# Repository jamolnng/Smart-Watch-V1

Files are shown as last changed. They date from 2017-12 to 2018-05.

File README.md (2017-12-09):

# Smart Watch

An open source smart watch based on a PIC32 microcontroller. The original idea came from http://jared.geek.nz/2014/jul/oshw-oled-watch and many of the design ideas came from here

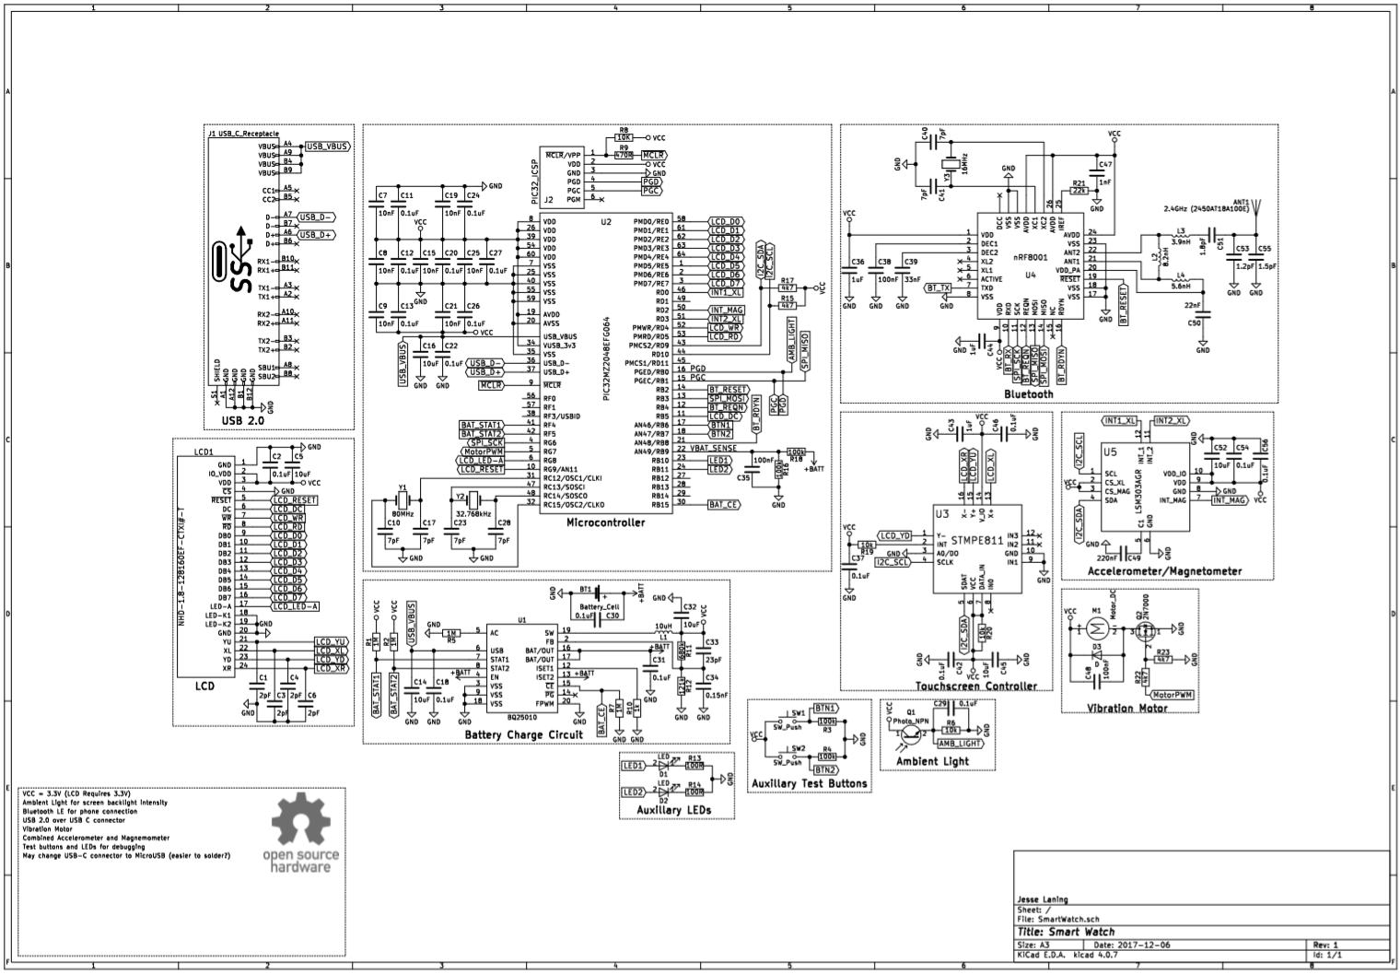
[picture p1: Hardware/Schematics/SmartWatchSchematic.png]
Schematic


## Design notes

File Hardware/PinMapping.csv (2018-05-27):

Physical Pin # | Full Pin Name | Pin Function |  | PPS |  |  | Notes
1 | AN17/ETXEN/RPE5/PMD5/RE5 | Input | Description | Pin Selection Register | Pin Selection Value | Physical Pin
2 | AN16/ETXD0/PMD6/RE6 | INT1_XL | Accelerometer Interrupt 1 | INT1R | 0011 | 46
3 | AN15/ETXD1/PMD7/RE7 | INT2_XL | Accelerometer Interrupt 2 | INT4R | 0000 | 51
4 | AN14/C1IND/RPG6/SCK2/PMA5/RG6 | INT_MAG | Magnemometer Interrupt | INT3R | 0000 | 50
5 | AN13/C1INC/RPG7/SDA4/PMA4/RG7 | BAT_STAT1 | Battery status pin 1 | RPF4R | 0000 | 41
6 | AN12/C2IND/RPG8/SCL4/PMA3/RG8 | BAT_STAT2 | Battery status pin 2 | RPF5R | 0000 | 42
7 | VSS | AMB_LIGHT | Ambient light analog input | RPB0R | 0000 | 16 | Analog/Do I really need this?
8 | VDD | BT_RDYN | ACI device ready indication | RPB8R | 0000 | 21 | Bluetooth: to figure out function
9 | MCLR | BTN1 | Button 1 input | PRB6R | 0000 | 17 | Do I really need these?
10 | AN11/C2INC/RPG9/PMA2/RG9 | BTN2 | Button 2 input | RPB7R | 0000 | 18
11 | AN45/C1INA/RPB5/RB5 | VBAT_SENSE | Battery voltage sense | × | × | 22 | Analog (AN49/RB9)
12 | AN4/C1INB/RB4 | T_INT | Touch Cont. Interrupt | RPF0R | 0000 | 56
13 | AN3/C2INA/RPB3/RB3
14 | AN2/C2INB/RPB2/RB2 | Output | Description | Pin Selection Register | Pin Selection Value | Physical Pin
15 | PGEC1/VREF-/CVREF-/AN1/RPB1/RB1 | BAT_CE | Battery charge enable | RPB15R | 0000 | 30
16 | PGED1/VREF+/CVREF+/AN0/RPB0/PMA6/RB0 | MotorPWM | Vibration Motor PWM | RPG7R | 1011 | 5
17 | PGEC2/AN46/RPB6/RB6 | LCD_LED-A | LCD Backlight Anode (PWM) | RPG8R | 1011 | 6
18 | PGED2/AN47/RPB7/RB7 | LCD_RESET | LCD Active LOW Reset | RPG9R | 0000 | 10
19 | AVDD | LCD_DC | LCD Data / Command selection | RPB5R | 0000 | 11
20 | AVSS | BT_REQN | ACI request pin | RPB4R | 0000 | 12 | Bluetooth: to figure out function
21 | AN48/RPB8/PMA10/RB8 | BT_RESET | Active LOW Reset Bluetooth | RPB2R | 0000 | 14
22 | AN49/RPB9/PMA7/RB9 | LED1 | LED 1 | RPB10R | 0000 | 23 | Do I really need these? (RB11 Not PPS)
23 | TMS/CVREFOUT/AN5/RPB10/PMA13/RB10 | LED2 | LED 2 | × | × | 24
24 | TDO/AN6/PMA12/RB11
25 | VSS | SPI | Description | Pin Selection Register | Pin Selection Value | Physical Pin
26 | VDD | SPI_SCK | SPI Clock | × | × | 4 | SPI 2 (pg. 26)
27 | TCK/AN7/PMA11/RB12 | SPI_MOSI | SPI MOSI | SDI2R | 0101 | 13
28 | TDI/AN8/RB13 | SPI_MISO | SPI MISO | RPB3R | 0110 | 15
29 | AN9/RPB14/SCK3/PMA1/RB14
30 | AN10/EMDC/AEMDC/RPB15/OCFB/PMA0/RB15 | I²C | Description | Pin Selection Register | Pin Selection Value | Physical Pin
31 | OSC1/CLKI/RC12 | I2C_SCL | I²C Clock (SCL) | × | × | 44 | I²C 1 (pg. 27)
32 | OSC2/CLKO/RC15 | I2C_SDA | I²C Data (SDA) | × | × | 43
33 | VBUS
34 | VUSB3v3 | PMP | Description | Pin Selection Register | Pin Selection Value | Physical Pin
35 | VSS | LCD_D0 | LCD Data 0 | × | × | 58
36 | D- | LCD_D1 | LCD Data 1 | × | × | 61
37 | D+ | LCD_D2 | LCD Data 2 | × | × | 62
38 | RPF3/USBID/RF3 | LCD_D3 | LCD Data 3 | × | × | 63
39 | VDD | LCD_D4 | LCD Data 4 | × | × | 64
40 | VSS | LCD_D5 | LCD Data 5 | × | × | 1
41 | RPF4/SDA5/PMA9/RF4 | LCD_D6 | LCD Data 6 | × | × | 2
42 | RPF5/SCL5/PMA8/RF5 | LCD_D7 | LCD Data 7 | × | × | 3
43 | AERXD0/ETXD2/RPD9/SDA1/PMCS2/PMA15/RD9 | LCD_WR | LCD Active LOW Write signal | × | × | 52
44 | ECOL/RPD10/SCL1/SCK4/RD10 | LCD_RD | LCD Active LOW Read signal | × | × | 53 | Will use on rev 1 because software might need to read from screen
45 | AERXCLK/AEREFCLK/ECRS/RPD11/PMCS1/PMA14/RD11
46 | AERXD1/ETXD3/RPD0/RTCC/INT0/RD0
47 | SOSCI/RPC13/RC13 | USB | Description | Pin Selection Register | Pin Selection Value | Physical Pin
48 | SOSCO/RPC14/T1CK/RC14 | D+ |  | × | × | 37
49 | EMDIO/AEMDIO/RPD1/SCK1/RD1 | D- |  | × | × | 36
50 | ETXERR/AETXEN/RPD2/SDA3/RD2
51 | AERXERR/ETXCLK/RPD3/SCL3/RD3 | ICSP | Description | Pin Selection Register | Pin Selection Value | Physical Pin
52 | SQICS0/RPD4/PMWR/RD4 | MCLR |  | × | × | 9 | Programming Pins
53 | SQICS1/RPD5/PMRD/RD5 | PGD |  | × | × | 16
54 | VDD | PGC |  | × | × | 15
55 | VSS
56 | ERXD3/AETXD1/RPF0/RF0 | INTERRUPTS | Description | Pin Selection Register | Pin Selection Value | Physical Pin
57 | TRCLK/SQICLK/ERXD2/AETXD0/RPF1/RF1 | INT0 | UNUSED | × | × | ×
58 | TRD0/SQID0/ERXD1/PMD0/RE0 | INT1 |  | INT1R | 0011 | 46
59 | VSS | INT2 | UNUSED | × | × | ×
60 | VDD | INT3 |  | INT3R | 0000 | 50
61 | TRD1/SQID1/ERXD0/PMD1/RE1 | INT4 |  | INT4R | 0000 | 51
62 | TRD2/SQID2/ERXDV/ECRSDV/AECRSDV/PMD2/RE2 |  |  |  |  |  | Probab gonna change processor and screen on rev 2 to support MIPI
63 | TRD3/SQID3/ERXCLK/EREFCLK/RPE3/PMD3/RE3
64 | AN18/ERXERR/PMD4/RE4 |  |  |  |  |  | PPS on pg 251

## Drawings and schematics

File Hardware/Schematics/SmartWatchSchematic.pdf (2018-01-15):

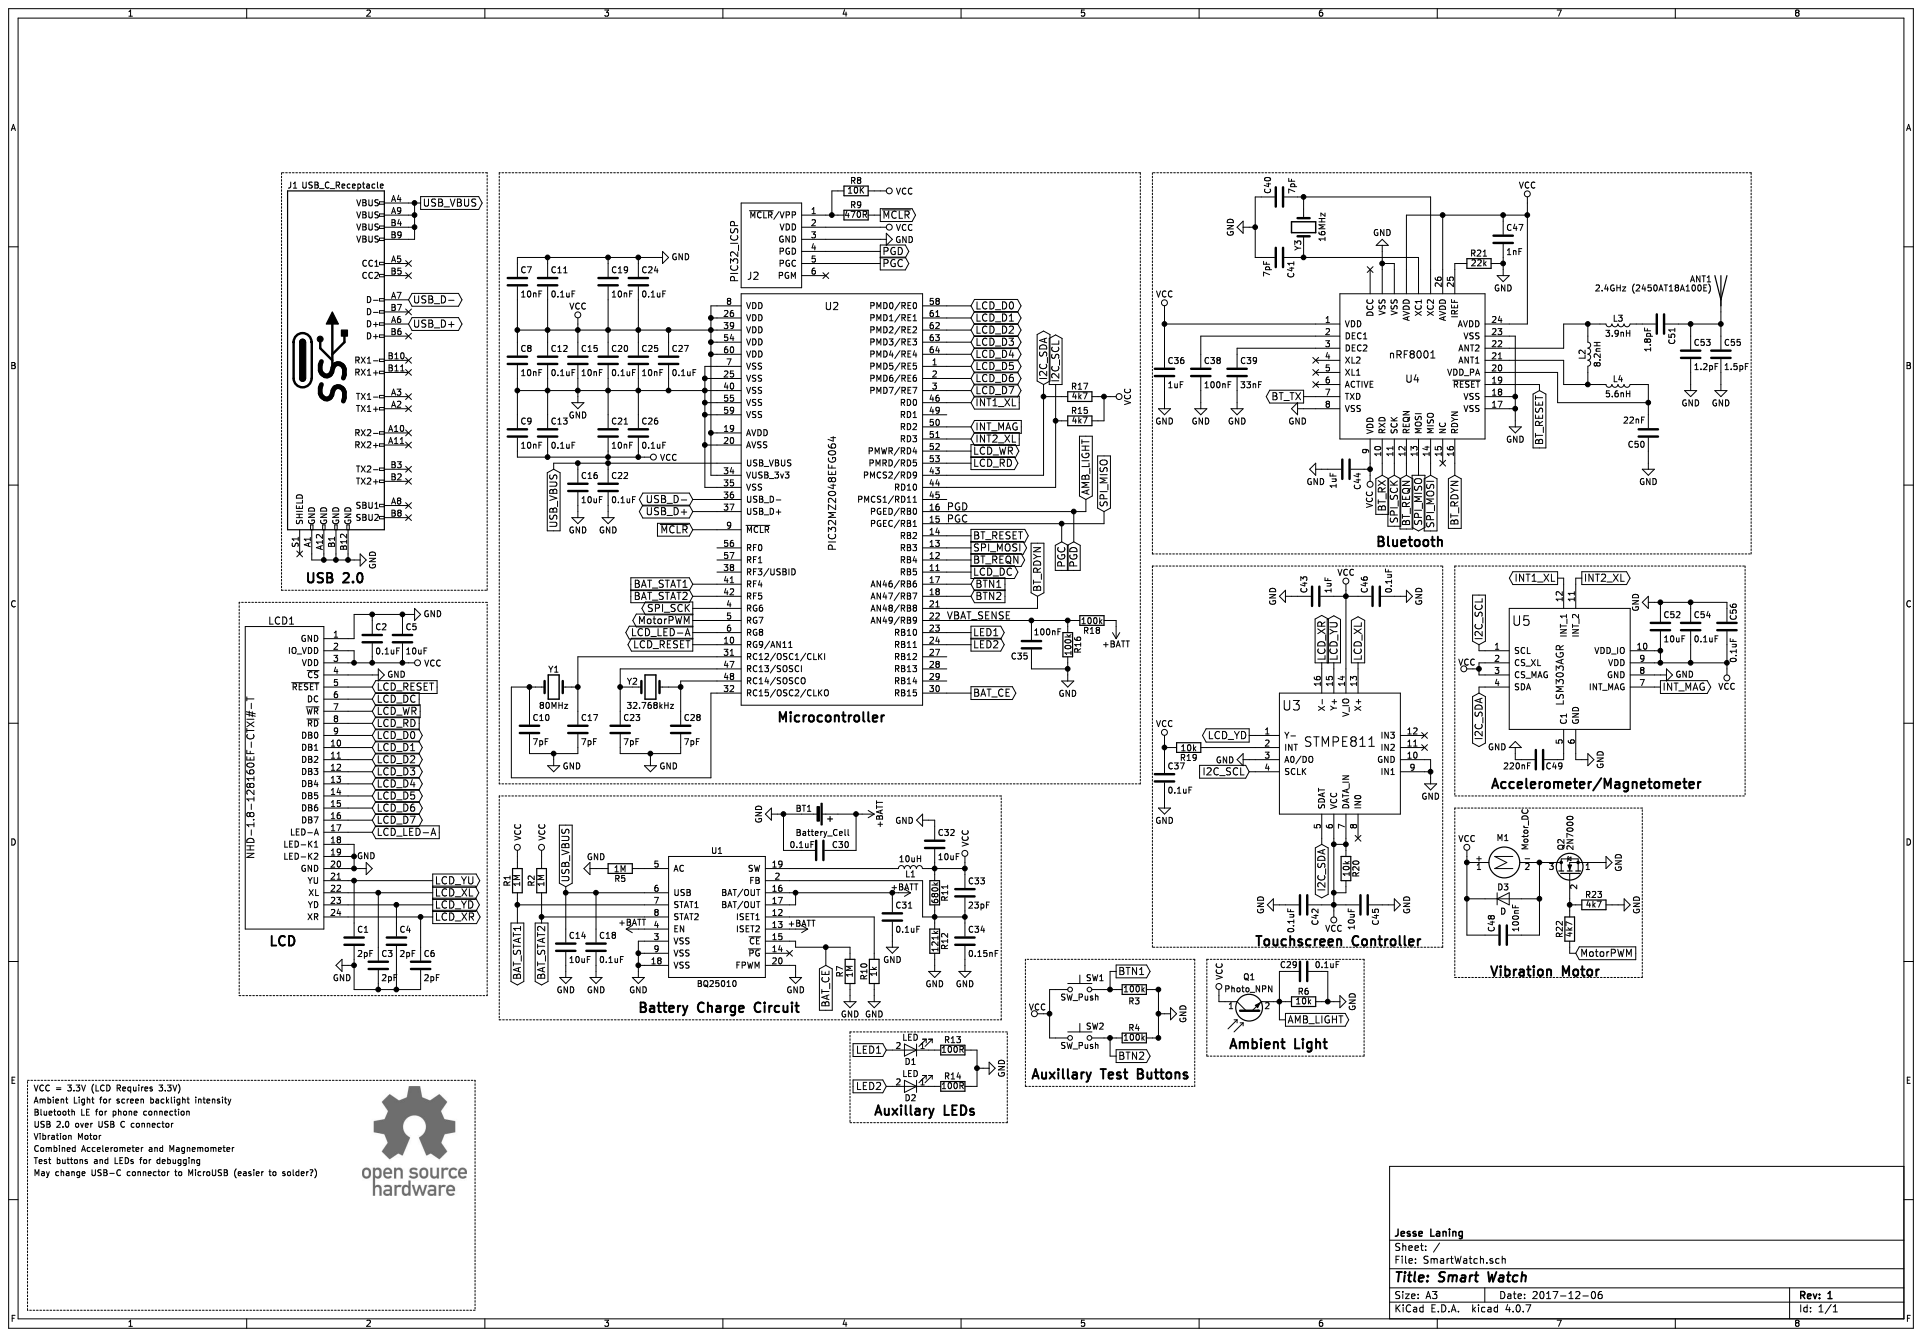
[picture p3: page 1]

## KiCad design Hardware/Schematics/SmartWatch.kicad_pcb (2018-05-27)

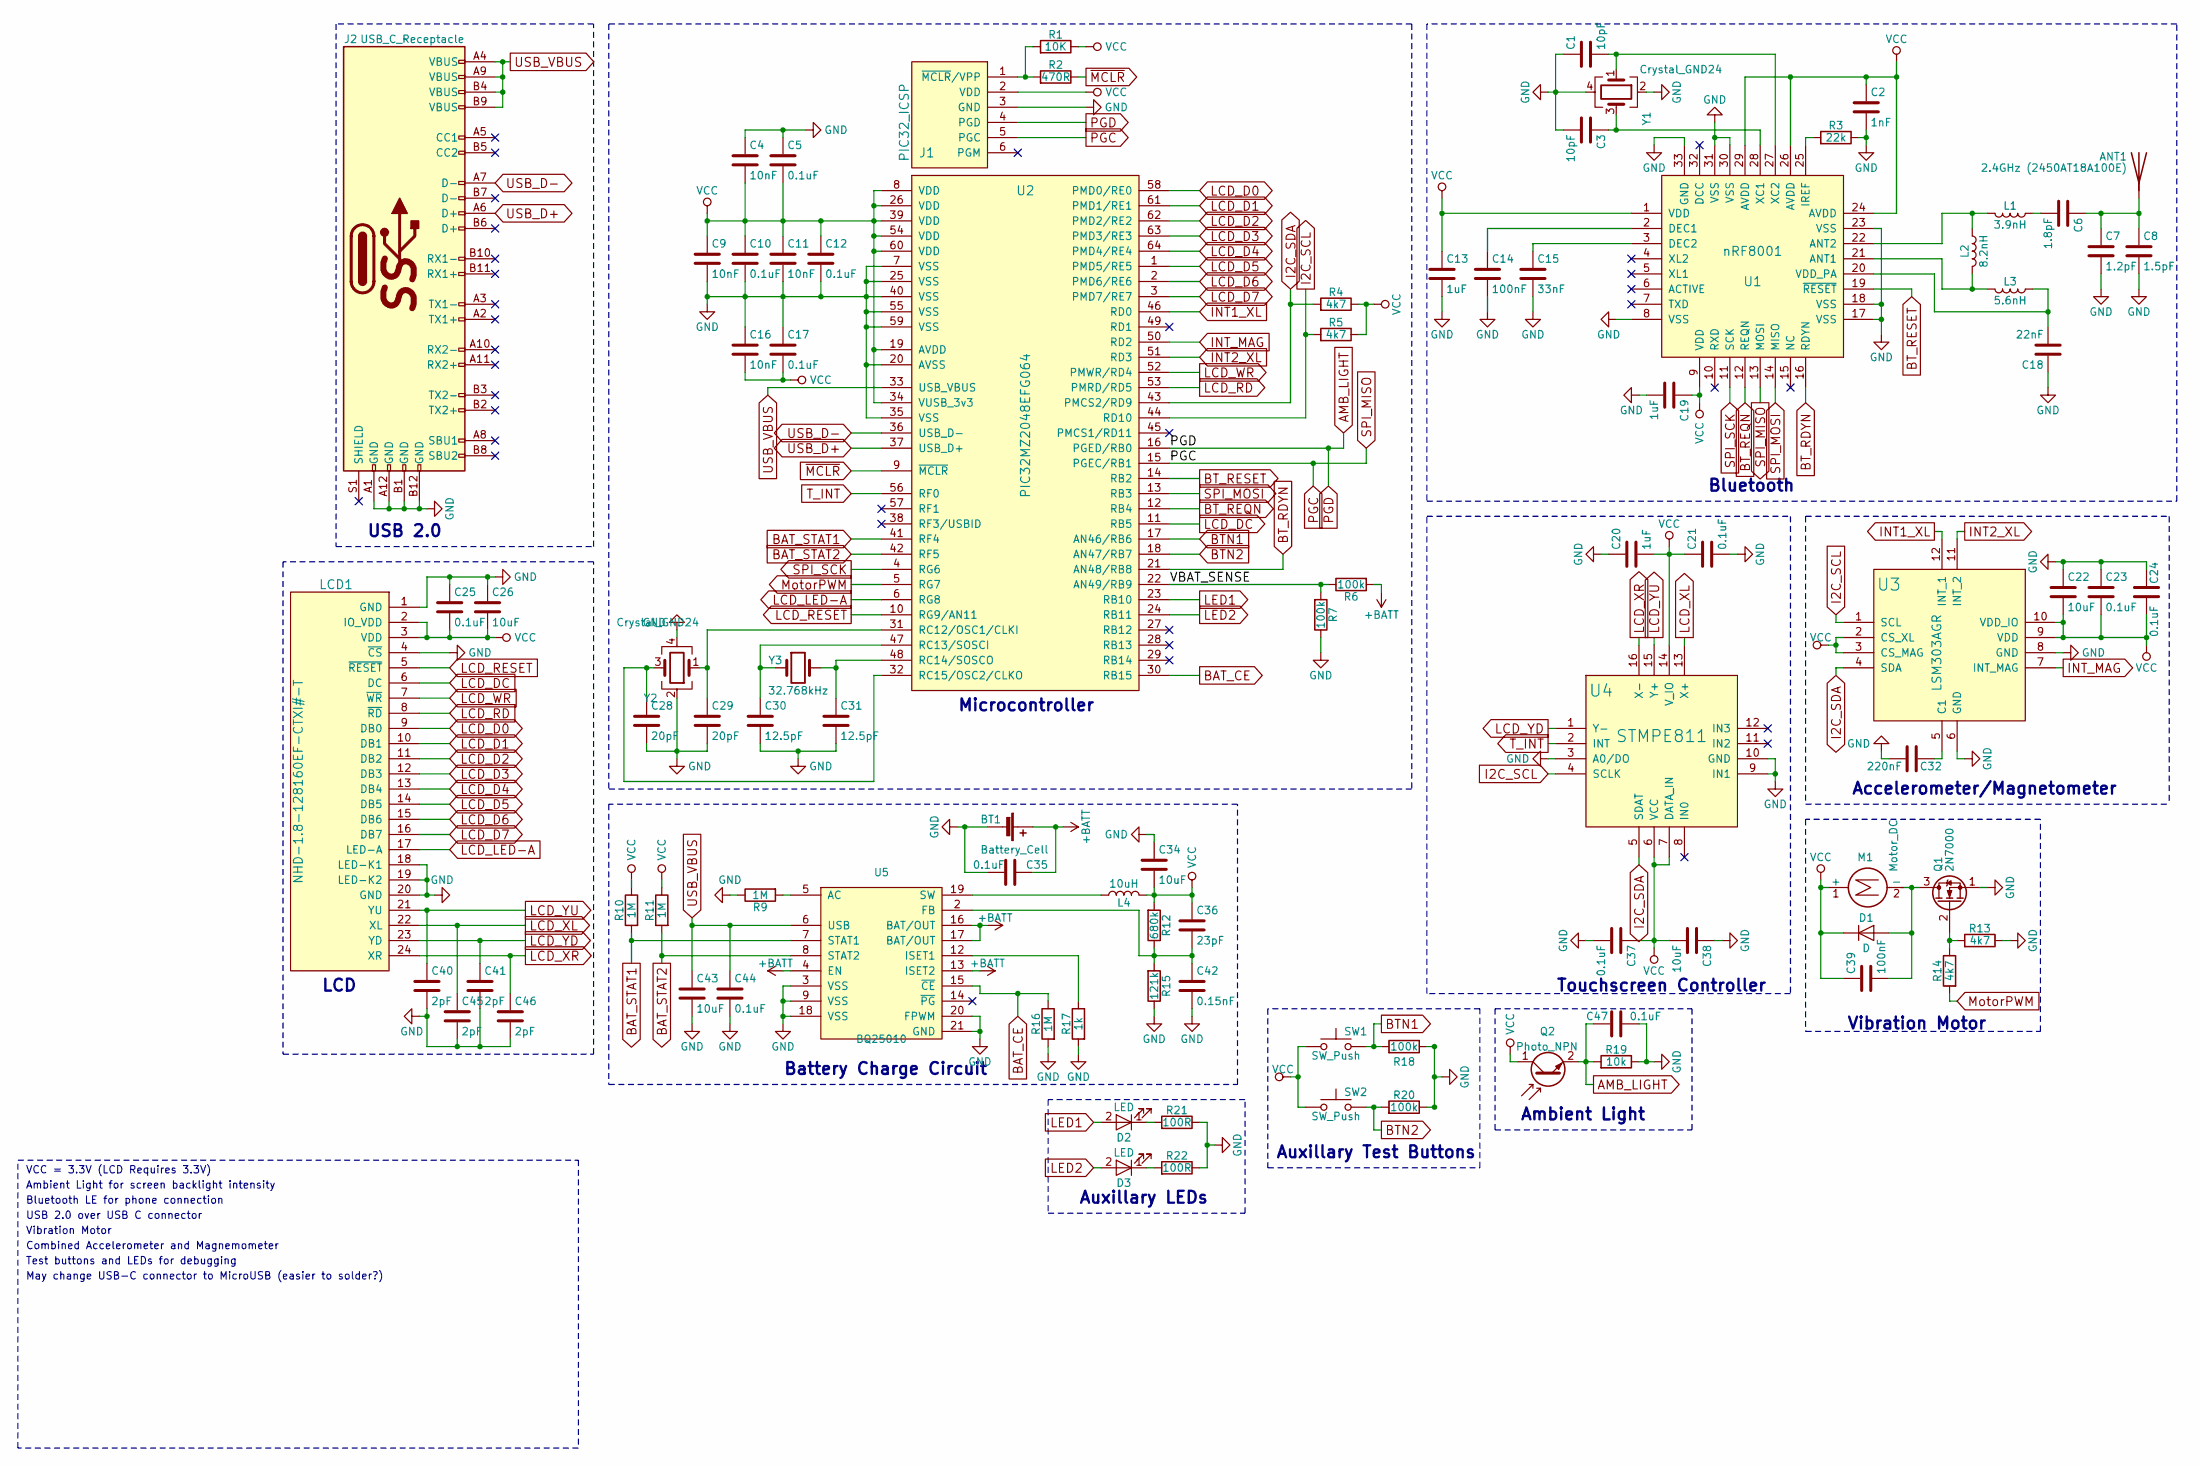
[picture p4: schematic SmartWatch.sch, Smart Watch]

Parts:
ANT1: 2.4GHz (2450AT18A100E); 2450AT18A100E
BT1: Battery_Cell; Pin_Header_Straight_2x01_Pitch2.54mm_SMD
C1, C3: 10pF; C_0603
C2: 1nF; C_0603
C4, C9, C11, C16: 10nF; C_0603
C5, C10, C12, C17, C21, C23, C24, C25, C35, C37, C44, C47: 0.1uF; C_0603
C6: 1.8pF; C_0603
C7: 1.2pF; C_0603
C8: 1.5pF; C_0603
C13, C19, C20: 1uF; C_0603
C14, C39: 100nF; C_0603
C15: 33nF; C_0603
C18: 22nF; C_0603
C22, C26, C34, C38, C43: 10uF; C_0603
C28, C29: 20pF; C_0603
C30, C31: 12.5pF; C_0603
C32: 220nF; C_0603
C36: 23pF; C_0603
C40, C41, C45, C46: 2pF; C_0603
C42: 0.15nF; C_0603
D1: D; D_0603
D2, D3: LED; LED_0603
J1: PIC32_ICSP; Pin_Header_Straight_2x03_Pitch1.00mm_SMD
J2: USB_C_Receptacle; USB_C_Receptacle_Amphenol_12401548E4-2A_CircularHoles
L1: 3.9nH; L_0603
L2: 8.2nH; L_0603
L3: 5.6nH; L_0603
L4: 10uH; L_0603
LCD1: NHD-1.8-128160EF-CTXI#-T
M1: Motor_DC; Pin_Header_Straight_2x01_Pitch2.54mm_SMD
Q1: 2N7000; TO-92_Molded_Narrow
Q2: Photo_NPN; D_3220
R1: 10K; R_0603
R2: 470R; R_0603
R3: 22k; R_0603
R4, R5, R13, R14: 4k7; R_0603
R6, R7, R18, R20: 100k; R_0603
R9, R10, R11, R16: 1M; R_0603
R12: 680k; R_0603
R15: 121k; R_0603
R17: 1k; R_0603
R19: 10k; R_0603
R21, R22: 100R; R_0603
SW1, SW2: SW_Push; SW_SPST_FSMSM
U1: nRF8001; QFN-32-1EP_5x5mm_Pitch0.5mm
U2: PIC32MZ2048EFG064; TQFP-64_10x10mm_Pitch0.5mm
U3: LSM303AGR; LGA-12_2x2mm_Pitch0.5mm
U4: STMPE811; QFN-20-1EP_4x4mm_Pitch0.5mm
U5: BQ25010; pvqfn-n20
Y1, Y2: Crystal_GND24; CX2520DB16000F0FDFC1
Y3: 32.768kHz; TFA322PG327KR

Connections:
+BATT: BT1.1 (+), C35.1, R6.2, U5.4 (EN), U5.13 (ISET2), U5.16 (BAT/OUT), U5.17 (BAT/OUT)
/VBAT_SENSE: R6.1, R7.2, U2.22 (AN49/RB9)
AMB_LIGHT: C47.1, J1.4 (PGD), Q2.2 (E), R19.2, U2.16 (PGED/RB0)
BAT_CE: R16.1, U2.30 (RB15), U5.15 (~CE)
BAT_STAT1: R10.2, U2.41 (RF4), U5.7 (STAT1)
BAT_STAT2: R11.2, U2.42 (RF5), U5.8 (STAT2)
BTN1: R18.2, SW1.2, U2.17 (AN46/RB6)
BTN2: R20.2, SW2.2, U2.18 (AN47/RB7)
BT_RDYN: U1.16 (RDYN), U2.21 (AN48/RB8)
BT_REQN: U1.12 (REQN), U2.12 (RB4)
BT_RESET: U1.19 (~RESET), U2.14 (RB2)
GND: BT1.2 (-), C1.1, C2.2, C3.2, C4.1, C5.1, C7.2, C8.2, C9.2, C10.2, C11.2, C12.2, C13.2, C14.2, C15.2, C16.1, C17.1, C18.1, C19.2, C20.1, C21.2, C22.1, C23.1, C24.1, C25.1, C26.1, C28.2, C29.2, C30.2, C31.2, C32.2, C34.1, C35.2, C37.2, C38.1, C40.2, C41.2, C42.2, C43.2, C44.2, C45.2, C46.2, C47.2, J1.3 (GND), J2.A1 (GND), J2.A12 (GND), J2.B1 (GND), J2.B12 (GND), LCD1.1 (GND), LCD1.4 (~CS), LCD1.18 (LED-K1), LCD1.19 (LED-K2), LCD1.20 (GND), Q1.1 (S), R3.1, R7.1, R9.1, R13.1, R15.1, R16.2, R17.2, R18.1, R19.1, R20.1, R21.1, R22.1, U1.8 (VSS), U1.17 (VSS), U1.18 (VSS), U1.23 (VSS), U1.30 (VSS), U1.31 (VSS), U1.33 (GND), U2.7 (VSS), U2.20 (AVSS), U2.25 (VSS), U2.35 (VSS), U2.40 (VSS), U2.55 (VSS), U2.59 (VSS), U3.6 (GND), U3.8 (GND), U4.3 (A0/DO), U4.9 (IN1), U4.10 (GND), U5.3 (VSS), U5.9 (VSS), U5.18 (VSS), U5.20 (FPWM), U5.21 (GND), Y1.2, Y1.4, Y2.2, Y2.4; also elsewhere on the board
I2C_SCL: R5.2, U2.44 (RD10), U3.1 (SCL), U4.4 (SCLK)
I2C_SDA: R4.2, U2.43 (PMCS2/RD9), U3.4 (SDA), U4.5 (SDAT)
INT1_XL: U2.46 (RD0), U3.12 (INT_1)
INT2_XL: U2.51 (RD3), U3.11 (INT_2)
INT_MAG: U2.50 (RD2), U3.7 (INT_MAG)
LCD_D0: LCD1.9 (DB0), U2.58 (PMD0/RE0)
LCD_D1: LCD1.10 (DB1), U2.61 (PMD1/RE1)
LCD_D2: LCD1.11 (DB2), U2.62 (PMD2/RE2)
LCD_D3: LCD1.12 (DB3), U2.63 (PMD3/RE3)
LCD_D4: LCD1.13 (DB4), U2.64 (PMD4/RE4)
LCD_D5: LCD1.14 (DB5), U2.1 (PMD5/RE5)
LCD_D6: LCD1.15 (DB6), U2.2 (PMD6/RE6)
LCD_D7: LCD1.16 (DB7), U2.3 (PMD7/RE7)
LCD_DC: LCD1.6 (DC), U2.11 (RB5)
LCD_LED-A: LCD1.17 (LED-A), U2.6 (RG8)
LCD_RD: LCD1.8 (~RD), U2.53 (PMRD/RD5)
LCD_RESET: LCD1.5 (~RESET), U2.10 (RG9/AN11)
LCD_WR: LCD1.7 (~WR), U2.52 (PMWR/RD4)
LCD_XL: C45.1, LCD1.22 (XL), U4.13 (X+)
LCD_XR: C46.1, LCD1.24 (XR), U4.16 (X-)
LCD_YD: C41.1, LCD1.23 (YD), U4.1 (Y-)
LCD_YU: C40.1, LCD1.21 (YU), U4.15 (Y+)
LED1: D2.2 (A), U2.23 (RB10)
LED2: D3.2 (A), U2.24 (RB11)
MotorPWM: R14.2, U2.5 (RG7)
unnamed: ANT1.1, C6.1, C7.1, C8.1
unnamed: C1.2, U1.27 (XC2), Y1.1
unnamed: C3.1, U1.28 (XC1), Y1.3
unnamed: C6.2, L1.1
unnamed: C14.1, U1.2 (DEC1)
unnamed: C15.1, U1.3 (DEC2)
unnamed: C18.2, L3.1, U1.20 (VDD_PA)
unnamed: C28.1, U2.32 (RC15/OSC2/CLKO), Y2.3
unnamed: C29.1, U2.31 (RC12/OSC1/CLKI), Y2.1
unnamed: C30.1, U2.47 (RC13/SOSCI), Y3.1
unnamed: C31.1, U2.48 (RC14/SOSCO), Y3.2
unnamed: C32.1, U3.5 (C1)
unnamed: C36.2, C42.1, R12.1, R15.2, U5.2 (FB)
unnamed: C39.2, D1.2 (A), M1.2 (-), Q1.3 (D)
unnamed: D2.1 (K), R21.2
unnamed: D3.1 (K), R22.2
unnamed: J1.1 (~MCLR~/VPP), R1.2, R2.2
unnamed: L1.2, L2.1, U1.22 (ANT2)
unnamed: L2.2, L3.2, U1.21 (ANT1)
unnamed: L4.1, U5.19 (SW)
unnamed: Q1.2 (G), R13.2, R14.1
unnamed: R3.2, U1.25 (IREF)
unnamed: R9.2, U5.5 (AC)
unnamed: R17.1, U5.12 (ISET1)
PGC: J1.5 (PGC), U1.13 (MOSI), U2.15 (PGEC/RB1)
SPI_MOSI: U1.14 (MISO), U2.13 (RB3)
SPI_SCK: U1.11 (SCK), U2.4 (RG6)
T_INT: U2.56 (RF0), U4.2 (INT)
USB_D+: J2.A6 (D+), U2.37 (USB_D+)
USB_D-: J2.A7 (D-), U2.36 (USB_D-)
USB_VBUS: C43.1, C44.1, J2.A4 (VBUS), J2.A9 (VBUS), J2.B4 (VBUS), J2.B9 (VBUS), U2.33 (USB_VBUS), U5.6 (USB)
VCC: C2.1, C4.2, C5.2, C9.1, C10.1, C11.1, C12.1, C13.1, C16.2, C17.2, C19.1, C20.2, C21.1, C22.2, C23.2, C24.2, C25.2, C26.2, C34.2, C36.1, C37.1, C38.2, C39.1, D1.1 (K), J1.2 (VDD), L4.2, LCD1.2 (IO_VDD), LCD1.3 (VDD), M1.1 (+), Q2.1 (C), R1.1, R4.1, R5.1, R10.1, R11.1, R12.2, SW1.1, SW2.1, U1.1 (VDD), U1.9 (VDD), U1.24 (AVDD), U1.26 (AVDD), U1.29 (AVDD), U2.8 (VDD), U2.19 (AVDD), U2.26 (VDD), U2.34 (VUSB_3v3), U2.39 (VDD), U2.54 (VDD), U2.60 (VDD), U3.2 (CS_XL), U3.3 (CS_MAG), U3.9 (VDD), U3.10 (VDD_IO), U4.6 (VCC), U4.7 (DATA_IN), U4.14 (V_IO); also elsewhere on the board
~MCLR: R2.1, U2.9 (~MCLR)

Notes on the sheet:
Microcontroller
Bluetooth
USB 2.0
Vibration Motor
LCD
Ambient Light
Touchscreen Controller
Accelerometer/Magnetometer
Auxillary Test Buttons
Auxillary LEDs
VCC = 3.3V (LCD Requires 3.3V)
Battery Charge Circuit
Ambient Light for screen backlight intensity
Bluetooth LE for phone connection
USB 2.0 over USB C connector
Combined Accelerometer and Magnemometer
Test buttons and LEDs for debugging
May change USB-C connector to MicroUSB (easier to solder?)

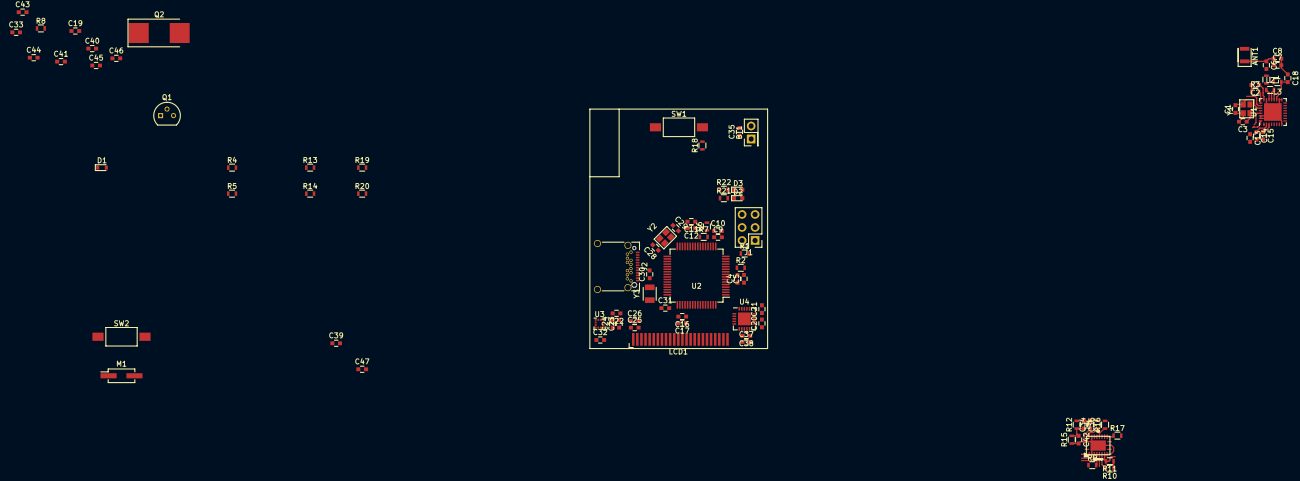
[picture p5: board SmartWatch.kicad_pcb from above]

Board: 2 copper layers, 93 parts (0 on the bottom side), 70 nets.

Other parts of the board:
C33: 0.1uF; C_0603
R8: 10k; R_0603

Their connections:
GND: C33.2; also elsewhere on the board
VCC: C33.1, R8.1; also elsewhere on the board

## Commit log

2017-12-09 initial commit
    initial commit
    [SmartWatch.kicad_pcb, SmartWatch.sch]
2017-12-09 schematic drawing
2017-12-09 schematic image in readme
2017-12-09 change schematic image file type
2017-12-10 pin mapping
    laying out pin mapping in a excel sheet to make it easier to implement
    [PinMapping.xlsx]
2017-12-10 pin changes
    [SmartWatch.sch]
2017-12-10 pin map csv
    csv for easier viewing
    [PinMapping.csv]
2017-12-10 pin mapping
    [PinMapping.csv, PinMapping.xlsx]
2017-12-14 pin mapping
    removed empty columns
    [PinMapping.xlsx]
2018-01-15 Update schematic
    [SmartWatch.sch]
2018-01-15 Update pin mapping
    All pins have been mapped. Subject to change
    [PinMapping.csv, PinMapping.xlsx]
2018-01-15 Update Schematic
    Updated schematic to match pin mapping
    [PinMapping.xlsx]
2018-01-15 Can't append a commit? Lame
    [PinMapping.xlsx]
2018-01-15 fixed file organization
    [SmartWatch.sch]
2018-01-15 finish footprint selecting and started pcb
    [SmartWatch.sch, _saved_SmartWatch.sch]
2018-01-15 Working on schematic
    [SmartWatch.kicad_pcb, SmartWatch.sch, _saved_SmartWatch.sch]
2018-05-27 cant remember
    [PinMapping.csv, PinMapping.xlsx, SmartWatch.kicad_pcb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]
